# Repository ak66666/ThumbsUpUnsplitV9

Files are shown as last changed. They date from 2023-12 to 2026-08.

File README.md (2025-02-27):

# ThumbsUp! v9 ProMicro-Compatible MCU, Kailh Choc Switches

Multilevel 44/46 Key Contoured Keyboard.
2- or 3-key Thumb Cluster.

* ProMicro pin-compatible MCUs: Atmega32U4, RP2040
* Nice!nano (oritinal and clones) with battery for the bluetooth connectivity, power switch is supposed to be used.
* Supports ProGlide Cirque touchpad.
* Hot swap sockets for switches.
* Compact key spacing (18x17), large MX-size caps won't fit.

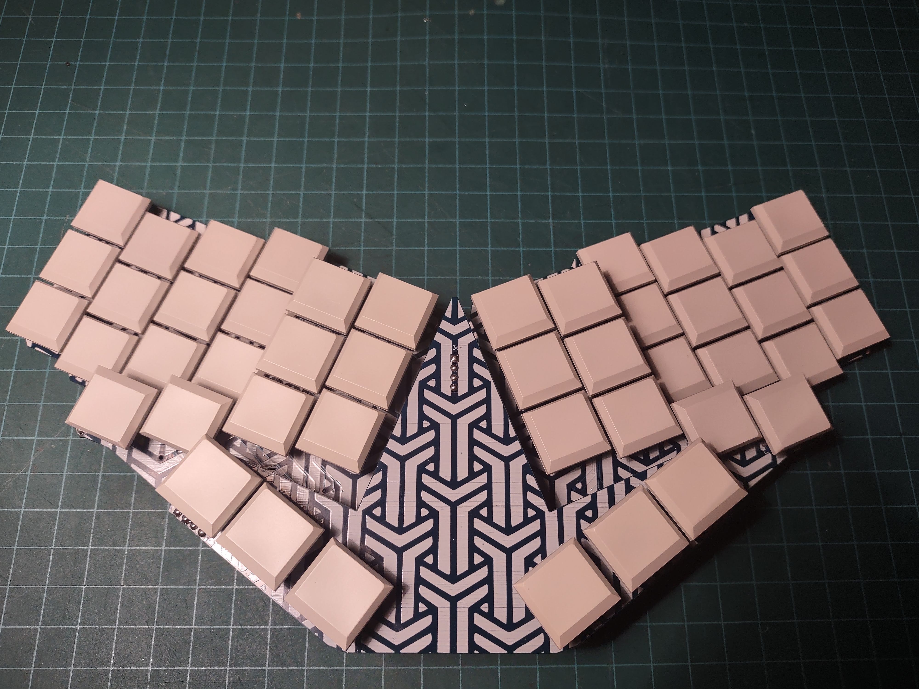
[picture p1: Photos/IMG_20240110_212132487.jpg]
Main view

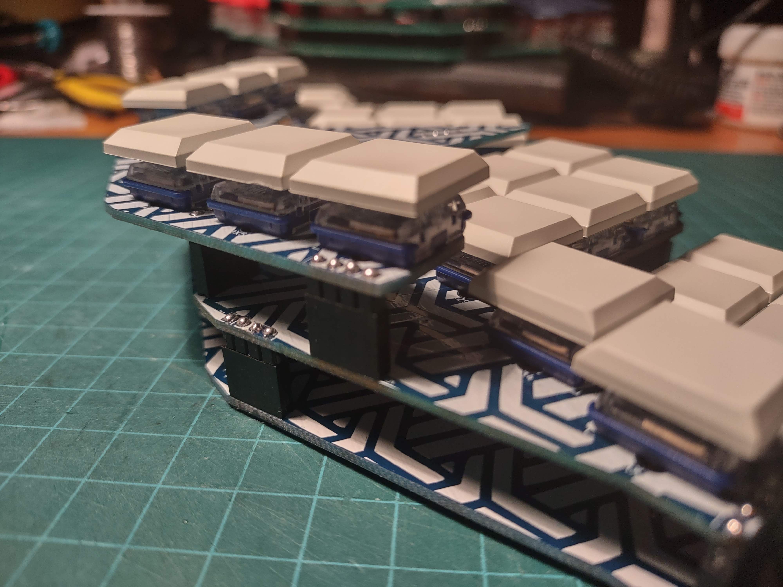
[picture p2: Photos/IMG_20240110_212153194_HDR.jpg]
3-key cluster stick out/hangs over the other plates


Other pictures in Photos folder.

# Firmware

Please refer to this article:
https://thumbsupkeyboards.blogspot.com/2024/02/source-files-and-default-firmware.html

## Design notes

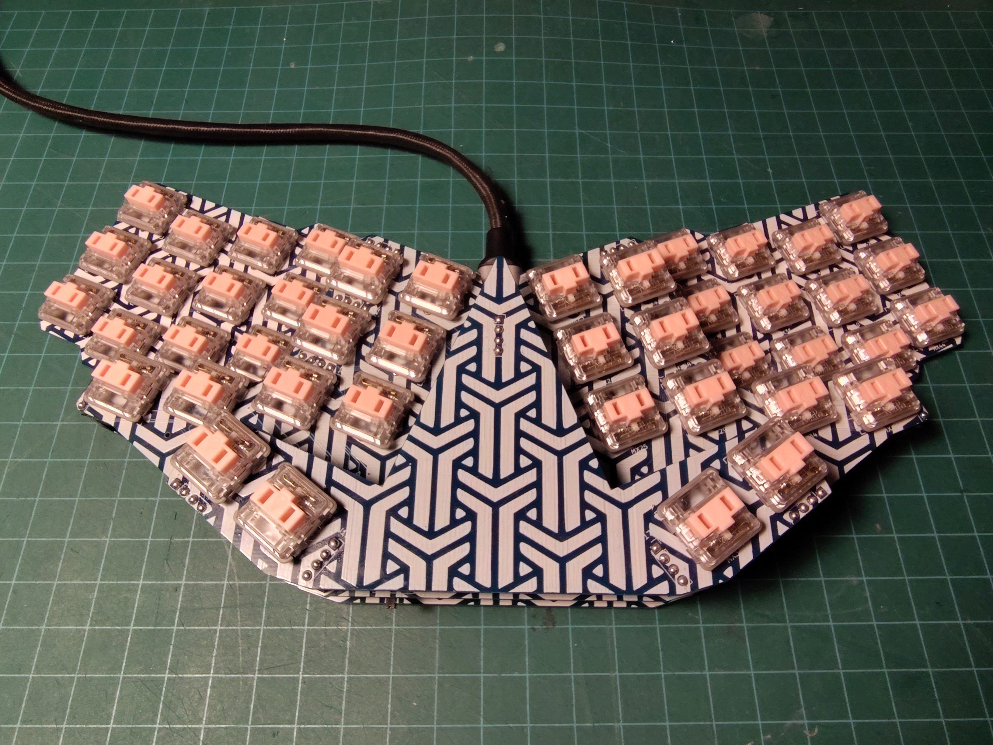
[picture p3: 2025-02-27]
Photos/IMG_20240401_223307706_HDR.jpg

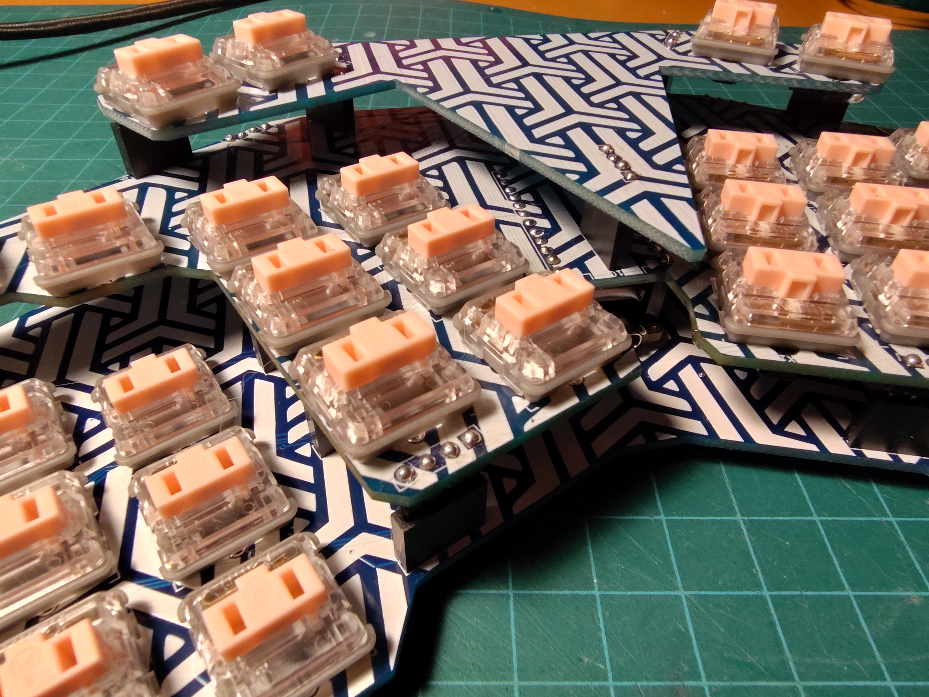
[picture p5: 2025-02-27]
Photos/IMG_20240401_223326087_HDR.jpg

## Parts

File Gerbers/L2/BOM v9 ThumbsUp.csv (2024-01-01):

Designator | Footprint | Comment
D46,D45,D44,D43,D42,D41,D40,D39,D38,D37,D36,D35,D34,D33,D32,D31,D30,D29,D28,D27,D26,D25,D24,D23,D22,D21,D20,D19,D18,D17,D16,D15,D14,D13,D12,D11,D10,D9,D8,D7,D6,D5,D4,D3,D2,D1 | D_SOD-123 | D_Small
R2,R1 | R_0805_2012Metric | 5.1K

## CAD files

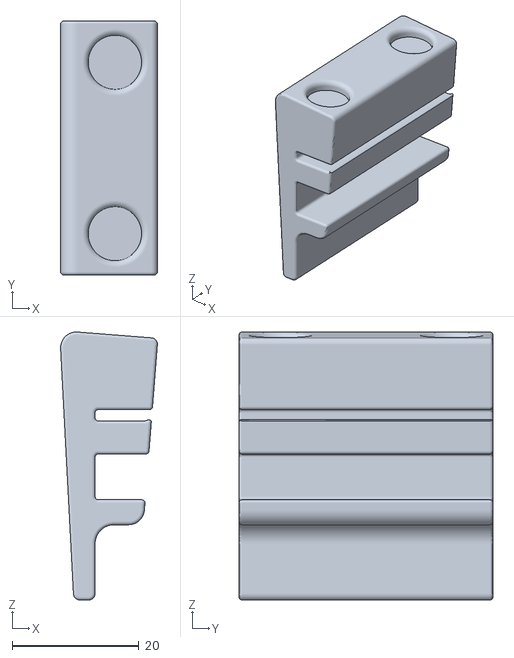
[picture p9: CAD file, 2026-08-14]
3D_parts/TU Heel.stl
15.3 x 40.0 x 42.2

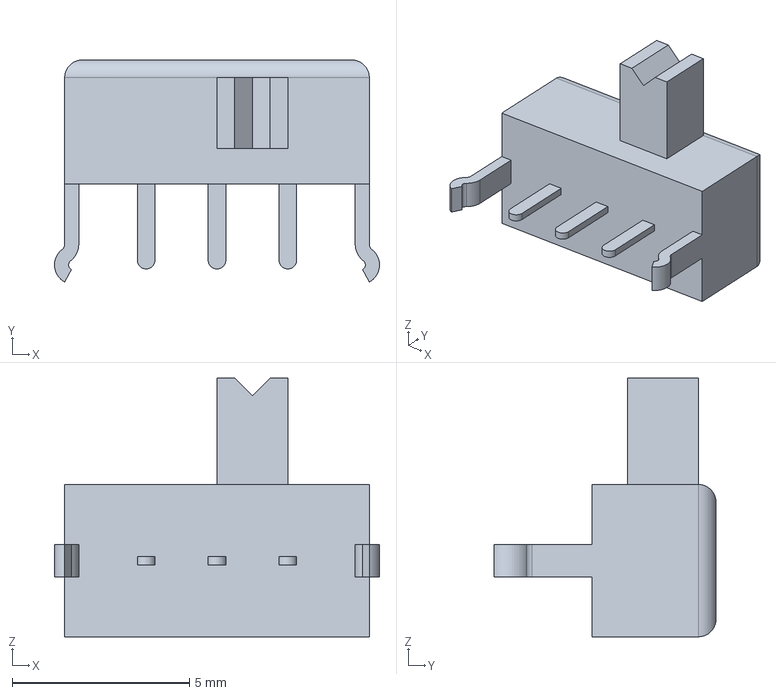
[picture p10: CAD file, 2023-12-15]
1825232-1/3D/1825232-1.stp
9.17 x 6.27 x 7.30 mm

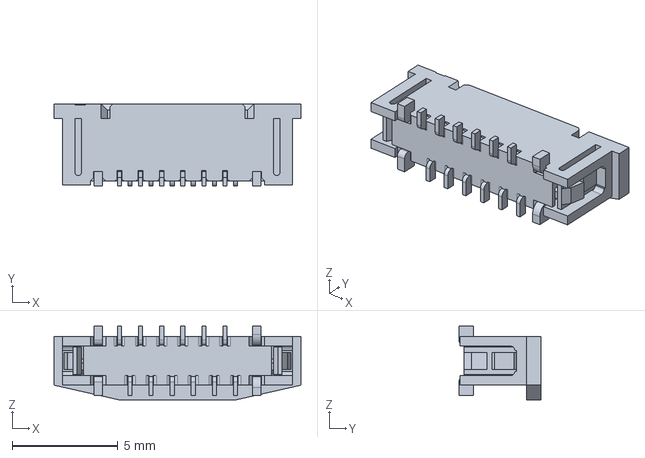
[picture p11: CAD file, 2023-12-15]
Molex 52559-1233/52559-1233/3D/52559-1233.stp
11.7 x 3.90 x 3.50 mm

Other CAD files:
1825232-1/Allegro/18252321.psm
1825232-1/DEHDL/1825232_1/chips/chips.prt
Molex 52559-1233/52559-1233/Allegro/525591233.psm
Molex 52559-1233/52559-1233/DEHDL/52559_1233/chips/chips.prt

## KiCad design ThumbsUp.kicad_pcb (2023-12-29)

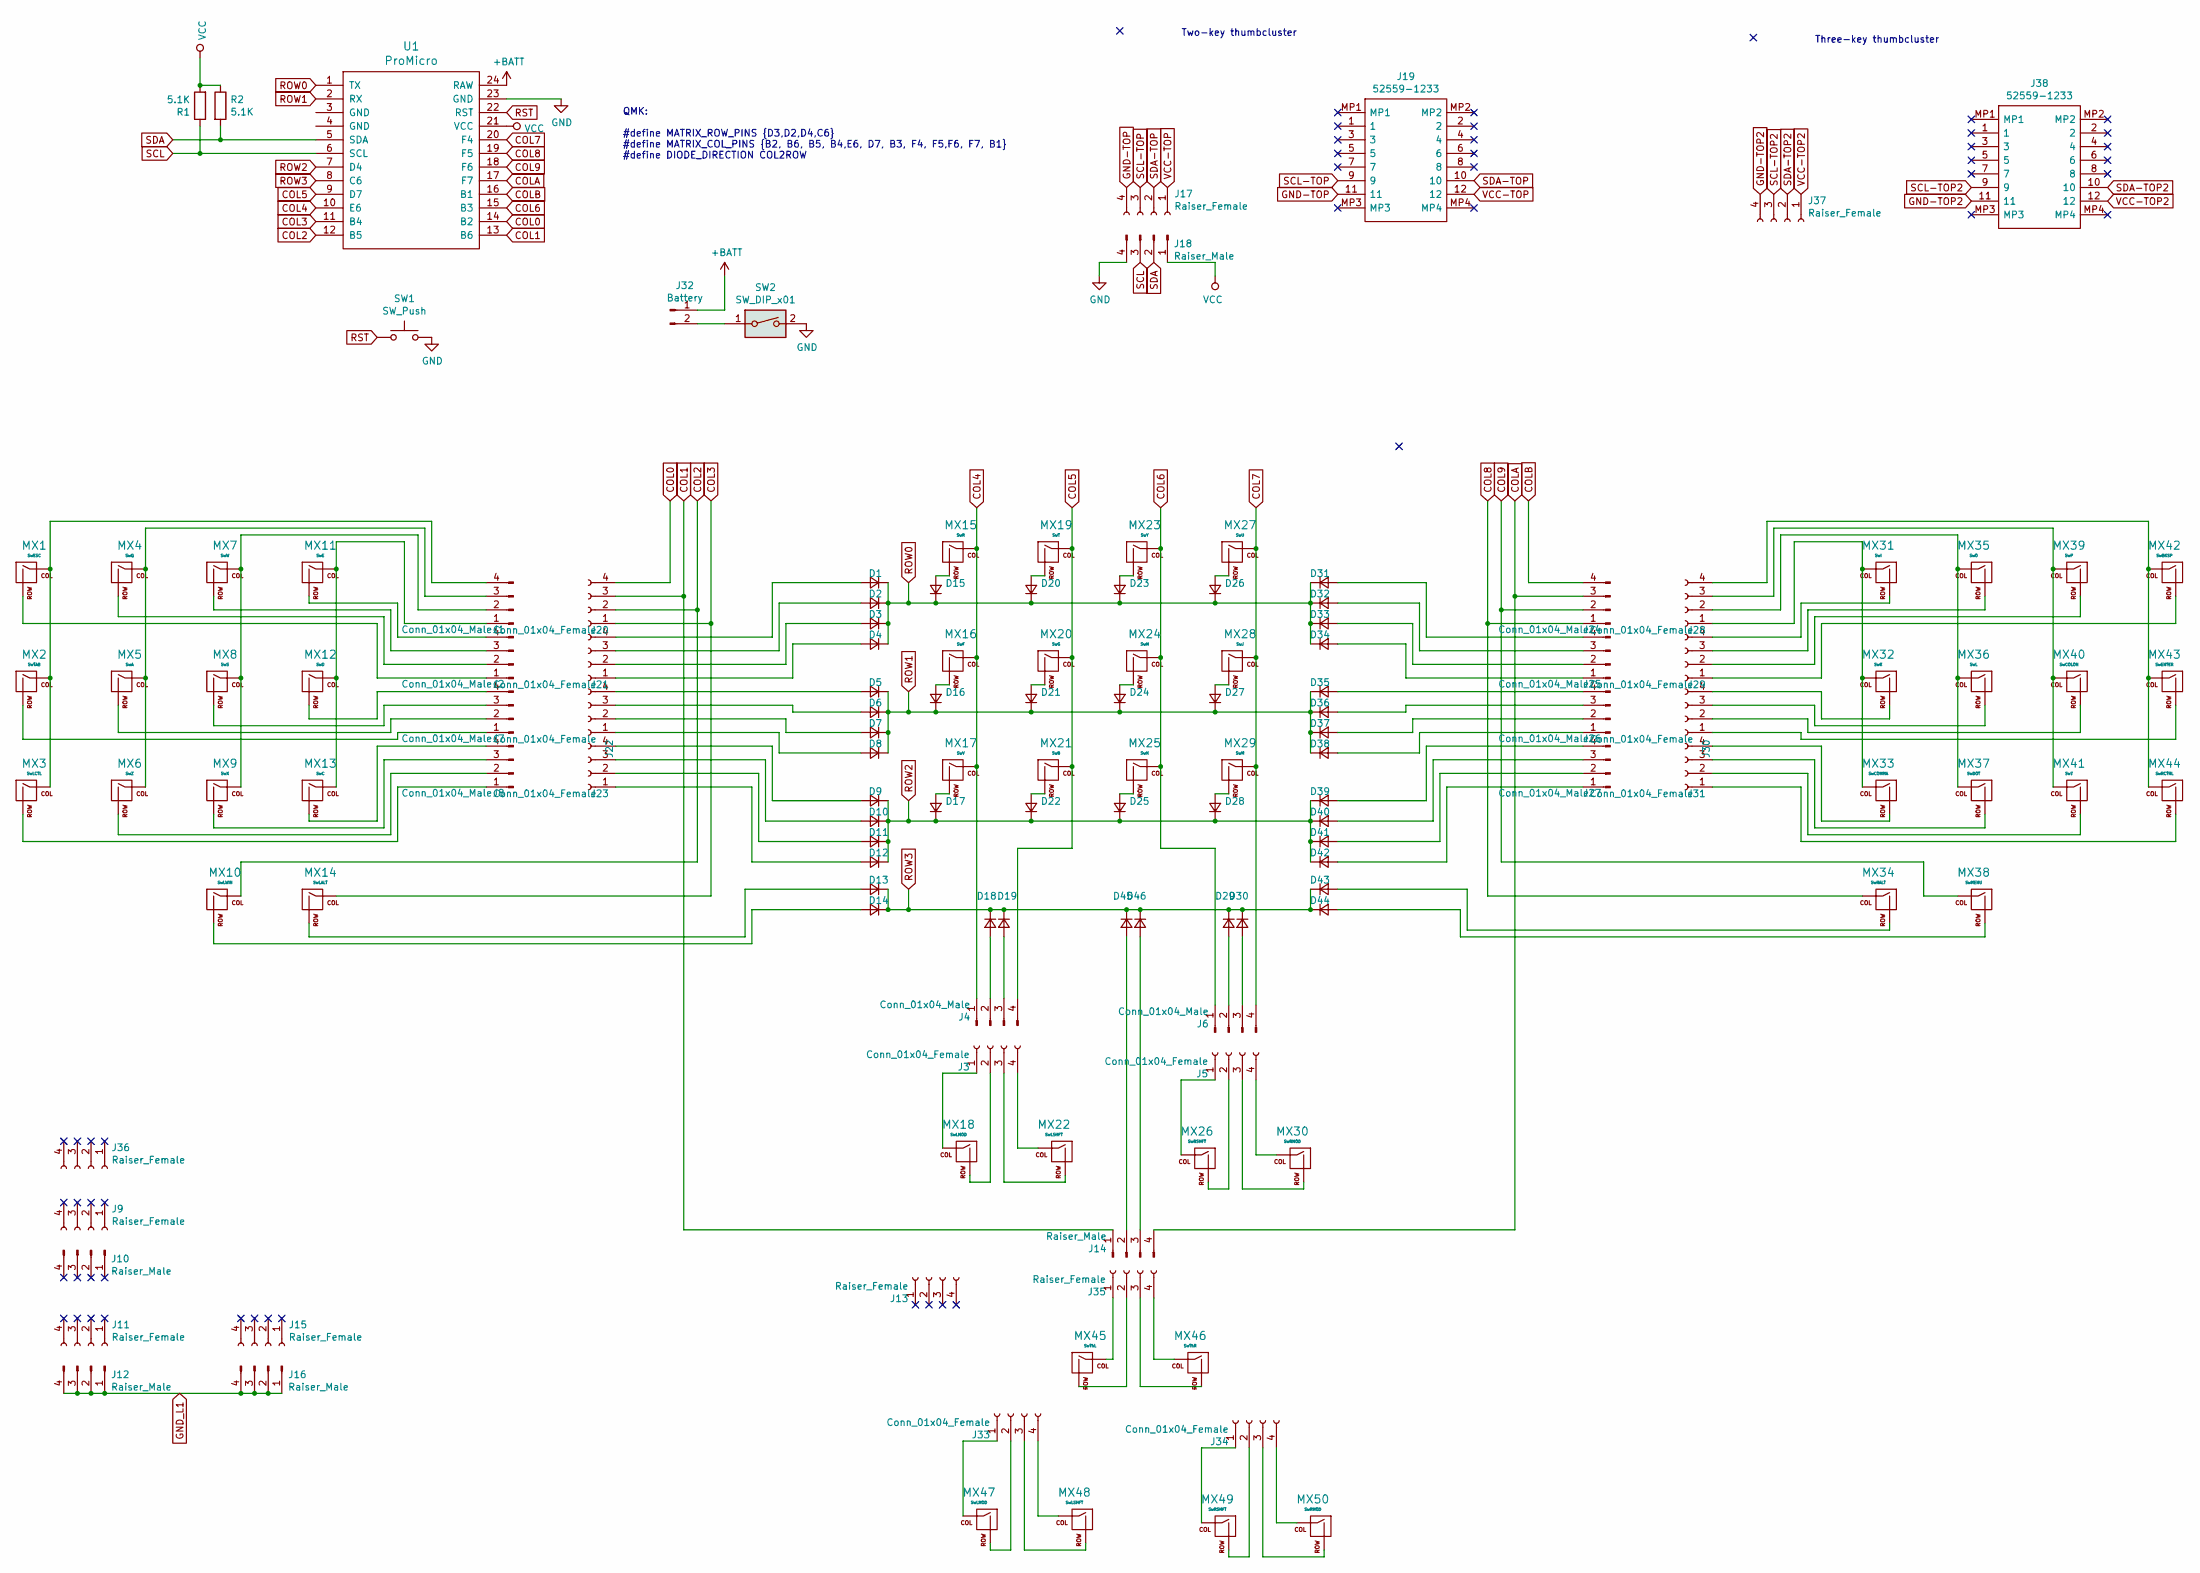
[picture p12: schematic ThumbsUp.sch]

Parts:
D1, D2, D3, D4, D5, D6, D7, D8, D9, D10, D11, D12, D13, D14, D15, D16, D17, D18, D19, D20, D21, D22, D23, D24, D25, D26, D27, D28, D29, D30, D31, D32, D33, D34, D35, D36, D37, D38, D39, D40, D41, D42, D43, D44, D45, D46: D_Small; D_SOD-123
J1, J2, J4, J6, J7, J8, J24, J25, J26, J27: Conn_01x04_Male; PinHeader_1x04_P2.54mm_Vertical
J3, J5, J20, J21, J22, J23, J28, J29, J30, J31, J33, J34: Conn_01x04_Female; PinSocket_1x04_P2.54mm_Vertical
J9, J11, J13, J15, J17, J35, J36, J37: Raiser_Female; PinSocket_1x04_P2.54mm_Vertical
J10, J12, J14, J16, J18: Raiser_Male; PinHeader_1x04_P2.54mm_Vertical
J19, J38: 52559-1233; 525591233; Mouser Part Number 538-52559-1233
J32: Battery; PinHeader_1x02_P2.54mm_Vertical
MX1: SwESC; Kailh_socket_PG1350_optional
MX2: SwTAB; Kailh_socket_PG1350_optional
MX3: SwLCTL; Kailh_socket_PG1350_optional
MX4: SwQ; Kailh_socket_PG1350_optional
MX5: SwA; Kailh_socket_PG1350_optional
MX6: SwZ; Kailh_socket_PG1350_optional
MX7: SwW; Kailh_socket_PG1350_optional
MX8: SwS; Kailh_socket_PG1350_optional
MX9: SwX; Kailh_socket_PG1350_optional
MX10: SwLWIN; Kailh_socket_PG1350_optional
MX11: SwE; Kailh_socket_PG1350_optional
MX12: SwD; Kailh_socket_PG1350_optional
MX13: SwC; Kailh_socket_PG1350_optional
MX14: SwLALT; Kailh_socket_PG1350_optional
MX15: SwR; Kailh_socket_PG1350_optional
MX16: SwF; Kailh_socket_PG1350_optional
MX17: SwV; Kailh_socket_PG1350_optional
MX18, MX47: SwLMOD; Kailh_socket_PG1350_optional
MX19: SwT; Kailh_socket_PG1350_optional
MX20: SwG; Kailh_socket_PG1350_optional
MX21: SwB; Kailh_socket_PG1350_optional
MX22, MX48: SwLSHFT; Kailh_socket_PG1350_optional
MX23: SwY; Kailh_socket_PG1350_optional
MX24: SwH; Kailh_socket_PG1350_optional
MX25: SwN; Kailh_socket_PG1350_optional
MX26, MX49: SwRSHFT; Kailh_socket_PG1350_optional
MX27: SwU; Kailh_socket_PG1350_optional
MX28: SwJ; Kailh_socket_PG1350_optional
MX29: SwM; Kailh_socket_PG1350_optional
MX30, MX50: SwRMOD; Kailh_socket_PG1350_optional
MX31: SwI; Kailh_socket_PG1350_optional
MX32: SwK; Kailh_socket_PG1350_optional
MX33: SwCOMMA; Kailh_socket_PG1350_optional
MX34: SwRALT; Kailh_socket_PG1350_optional
MX35: SwO; Kailh_socket_PG1350_optional
MX36: SwL; Kailh_socket_PG1350_optional
MX37: SwDOT; Kailh_socket_PG1350_optional
MX38: SwMENU; Kailh_socket_PG1350_optional
MX39: SwP; Kailh_socket_PG1350_optional
MX40: SwCOLON; Kailh_socket_PG1350_optional
MX41: Sw?; Kailh_socket_PG1350_optional
MX42: SwBKSP; Kailh_socket_PG1350_optional
MX43: SwENTER; Kailh_socket_PG1350_optional
MX44: SwRCTRL; Kailh_socket_PG1350_optional
MX45: SwThL; Kailh_socket_PG1350_optional
MX46: SwThR; Kailh_socket_PG1350_optional
R1, R2: 5.1K; R_0805_2012Metric
SW1: SW_Push; SKQG-1155865
SW2: SW_DIP_x01; 18252321
U1: ProMicro

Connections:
+BATT: J32.1, U1.24 (RAW)
COL0: J20.4, U1.14 (B2)
COL1: J14.1, J20.3, U1.13 (B6)
COL2: J20.2, MX10.1 (COL), U1.12 (B5)
COL3: J20.1, MX14.1 (COL), U1.11 (B4)
COL4: J4.1, MX15.1 (COL), MX16.1 (COL), MX17.1 (COL), U1.10 (E6)
COL5: J4.4, MX19.1 (COL), MX20.1 (COL), MX21.1 (COL), U1.9 (D7)
COL6: J6.1, MX23.1 (COL), MX24.1 (COL), MX25.1 (COL), U1.15 (B3)
COL7: J6.4, MX27.1 (COL), MX28.1 (COL), MX29.1 (COL), U1.20 (F4)
COL8: J24.1, MX34.1 (COL), U1.19 (F5)
COL9: J24.2, MX38.1 (COL), U1.18 (F6)
COLA: J14.4, J24.3, U1.17 (F7)
COLB: J24.4, U1.16 (B1)
GND: J18.4, SW1.2, SW2.2, U1.23 (GND)
GND-TOP: J17.4, J19.11
GND-TOP2: J37.4, J38.11
GND_L1: J12.1, J12.2, J12.3, J12.4, J16.1, J16.2, J16.3, J16.4
unnamed: D1.2 (A), J21.4
unnamed: D2.2 (A), J21.3
unnamed: D3.2 (A), J21.2
unnamed: D4.2 (A), J21.1
unnamed: D5.2 (A), J22.4
unnamed: D6.2 (A), J22.3
unnamed: D7.2 (A), J22.2
unnamed: D8.2 (A), J22.1
unnamed: D9.2 (A), J23.4
unnamed: D10.2 (A), J23.3
unnamed: D11.2 (A), J23.2
unnamed: D12.2 (A), J23.1
unnamed: D13.2 (A), MX14.2 (ROW)
unnamed: D14.2 (A), MX10.2 (ROW)
unnamed: D15.2 (A), MX15.2 (ROW)
unnamed: D16.2 (A), MX16.2 (ROW)
unnamed: D17.2 (A), MX17.2 (ROW)
unnamed: D18.2 (A), J4.2
unnamed: D19.2 (A), J4.3
unnamed: D20.2 (A), MX19.2 (ROW)
unnamed: D21.2 (A), MX20.2 (ROW)
unnamed: D22.2 (A), MX21.2 (ROW)
unnamed: D23.2 (A), MX23.2 (ROW)
unnamed: D24.2 (A), MX24.2 (ROW)
unnamed: D25.2 (A), MX25.2 (ROW)
unnamed: D26.2 (A), MX27.2 (ROW)
unnamed: D27.2 (A), MX28.2 (ROW)
unnamed: D28.2 (A), MX29.2 (ROW)
unnamed: D29.2 (A), J6.2
unnamed: D30.2 (A), J6.3
unnamed: D31.2 (A), J25.4
unnamed: D32.2 (A), J25.3
unnamed: D33.2 (A), J25.2
unnamed: D34.2 (A), J25.1
unnamed: D35.2 (A), J26.4
unnamed: D36.2 (A), J26.3
unnamed: D37.2 (A), J26.2
unnamed: D38.2 (A), J26.1
unnamed: D39.2 (A), J27.4
unnamed: D40.2 (A), J27.3
unnamed: D41.2 (A), J27.2
unnamed: D42.2 (A), J27.1
unnamed: D43.2 (A), MX34.2 (ROW)
unnamed: D44.2 (A), MX38.2 (ROW)
unnamed: D45.2 (A), J14.2
unnamed: D46.2 (A), J14.3
unnamed: J1.1, MX11.1 (COL), MX12.1 (COL), MX13.1 (COL)
unnamed: J1.2, MX7.1 (COL), MX8.1 (COL), MX9.1 (COL)
unnamed: J1.3, MX4.1 (COL), MX5.1 (COL), MX6.1 (COL)
unnamed: J1.4, MX1.1 (COL), MX2.1 (COL), MX3.1 (COL)
unnamed: J2.1, MX1.2 (ROW)
unnamed: J2.2, MX4.2 (ROW)
unnamed: J2.3, MX7.2 (ROW)
unnamed: J2.4, MX11.2 (ROW)
unnamed: J3.1, MX18.1 (COL)
unnamed: J3.2, MX18.2 (ROW)
unnamed: J3.3, MX22.2 (ROW)
unnamed: J3.4, MX22.1 (COL)
unnamed: J5.1, MX26.1 (COL)
unnamed: J5.2, MX26.2 (ROW)
unnamed: J5.3, MX30.2 (ROW)
unnamed: J5.4, MX30.1 (COL)
unnamed: J7.1, MX2.2 (ROW)
unnamed: J7.2, MX5.2 (ROW)
unnamed: J7.3, MX8.2 (ROW)
unnamed: J7.4, MX12.2 (ROW)
unnamed: J8.1, MX3.2 (ROW)
unnamed: J8.2, MX6.2 (ROW)
unnamed: J8.3, MX9.2 (ROW)
unnamed: J8.4, MX13.2 (ROW)
unnamed: J28.1, MX31.1 (COL), MX32.1 (COL), MX33.1 (COL)
unnamed: J28.2, MX35.1 (COL), MX36.1 (COL), MX37.1 (COL)
unnamed: J28.3, MX39.1 (COL), MX40.1 (COL), MX41.1 (COL)
unnamed: J28.4, MX42.1 (COL), MX43.1 (COL), MX44.1 (COL)
unnamed: J29.1, MX42.2 (ROW)
unnamed: J29.2, MX39.2 (ROW)
unnamed: J29.3, MX35.2 (ROW)
unnamed: J29.4, MX31.2 (ROW)
unnamed: J30.1, MX43.2 (ROW)
unnamed: J30.2, MX40.2 (ROW)
unnamed: J30.3, MX36.2 (ROW)
unnamed: J30.4, MX32.2 (ROW)
unnamed: J31.1, MX44.2 (ROW)
unnamed: J31.2, MX41.2 (ROW)
unnamed: J31.3, MX37.2 (ROW)
unnamed: J31.4, MX33.2 (ROW)
unnamed: J32.2, SW2.1
unnamed: J33.1, MX47.1 (COL)
unnamed: J33.2, MX47.2 (ROW)
unnamed: J33.3, MX48.2 (ROW)
unnamed: J33.4, MX48.1 (COL)
unnamed: J34.1, MX49.1 (COL)
unnamed: J34.2, MX49.2 (ROW)
unnamed: J34.3, MX50.2 (ROW)
unnamed: J34.4, MX50.1 (COL)
unnamed: J35.1, MX45.1 (COL)
unnamed: J35.2, MX45.2 (ROW)
unnamed: J35.3, MX46.2 (ROW)
unnamed: J35.4, MX46.1 (COL)
ROW0: D1.1 (K), D2.1 (K), D3.1 (K), D4.1 (K), D15.1 (K), D20.1 (K), D23.1 (K), D26.1 (K), D31.1 (K), D32.1 (K), D33.1 (K), D34.1 (K), U1.1 (TX)
ROW1: D5.1 (K), D6.1 (K), D7.1 (K), D8.1 (K), D16.1 (K), D21.1 (K), D24.1 (K), D27.1 (K), D35.1 (K), D36.1 (K), D37.1 (K), D38.1 (K), U1.2 (RX)
ROW2: D9.1 (K), D10.1 (K), D11.1 (K), D12.1 (K), D17.1 (K), D22.1 (K), D25.1 (K), D28.1 (K), D39.1 (K), D40.1 (K), D41.1 (K), D42.1 (K), U1.7 (D4)
ROW3: D13.1 (K), D14.1 (K), D18.1 (K), D19.1 (K), D29.1 (K), D30.1 (K), D43.1 (K), D44.1 (K), D45.1 (K), D46.1 (K), U1.8 (C6)
RST: SW1.1, U1.22 (RST)
SCL: J18.3, R1.1, U1.6 (SCL)
SCL-TOP: J17.3, J19.9
SCL-TOP2: J37.3, J38.9
SDA: J18.2, R2.2, U1.5 (SDA)
SDA-TOP: J17.2, J19.10
SDA-TOP2: J37.2, J38.10
VCC: J18.1, R1.2, R2.1, U1.21 (VCC)
VCC-TOP: J17.1, J19.12
VCC-TOP2: J37.1, J38.12

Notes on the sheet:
QMK: #define MATRIX_ROW_PINS {D3,D2,D4,C6} #define MATRIX_COL_PINS {B2, B6, B5, B4,E6, D7, B3, F4, F5,F6, F7, B1} #define DIODE_DIRECTION COL2ROW
Two-key thumbcluster
Three-key thumbcluster

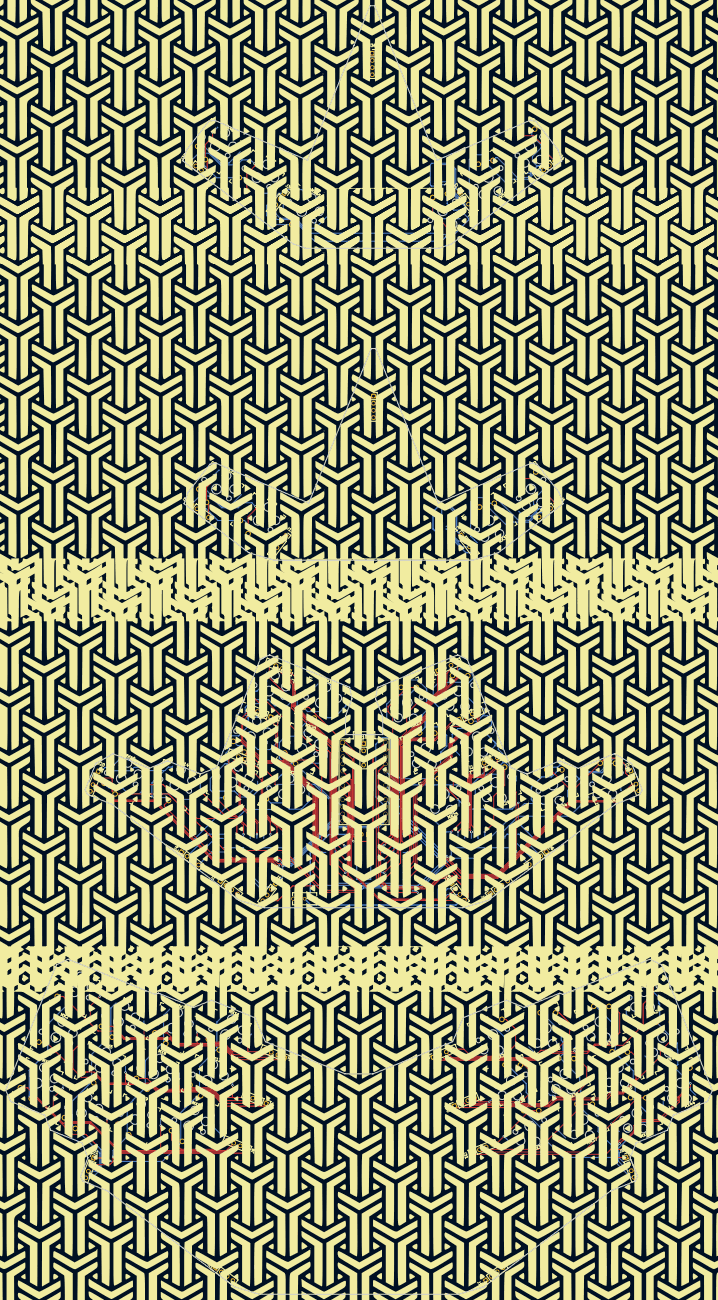
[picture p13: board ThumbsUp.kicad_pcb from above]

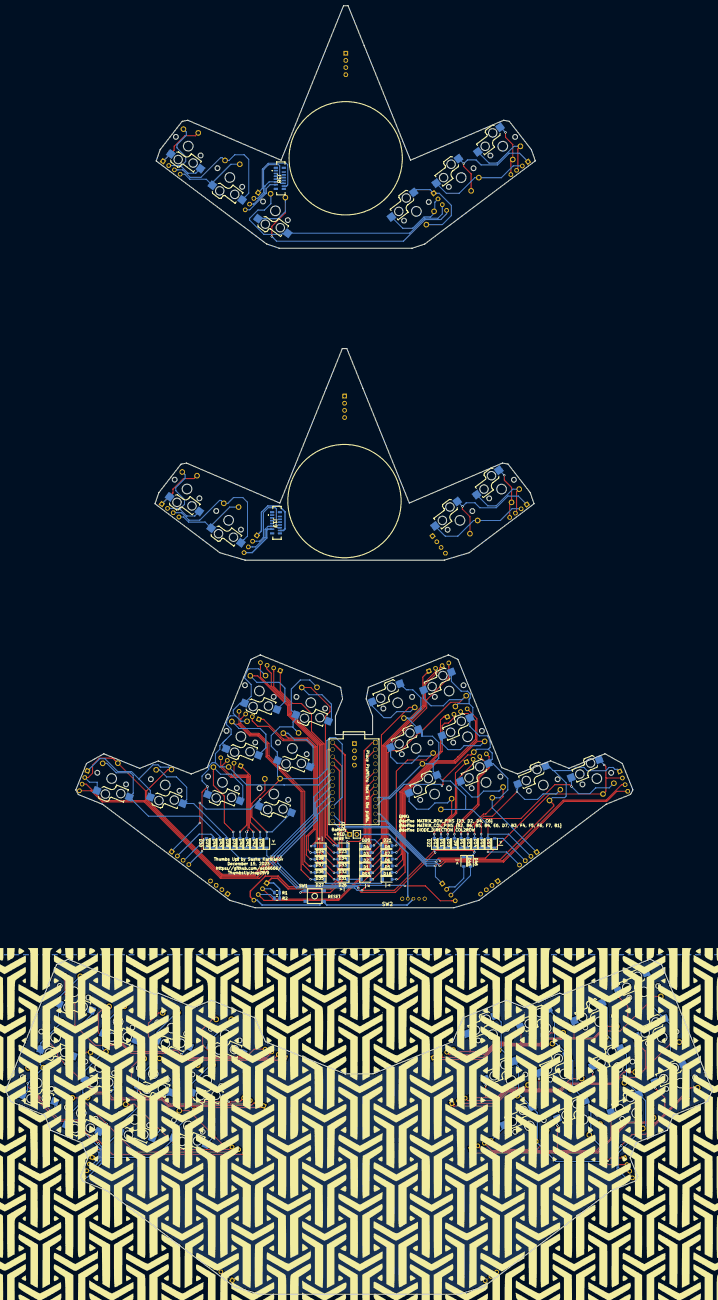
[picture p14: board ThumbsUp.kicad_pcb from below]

Board: 2 copper layers, 251.1 x 457.9 mm, 139 parts (52 on the bottom side), 130 nets.

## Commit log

2023-12-15 v9 Initial commit from v2.
    [1825232-1.SchLib, 1825232-1.stp, 18252321.PcbLib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]
2023-12-16 v9 Added the third key to the thumbcluster.
    [ThumbsUp.sch]
2023-12-27 v9 Redrew the lower PCB, added the silkscreens.
    [ThumbsUp.kicad_pcb, ThumbsUp.sch]
2024-01-01 v9 Gerbers generated
    [BOM v9 ThumbsUp.csv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]
2026-08-14 B9: Added an extended heel.
    [TU Heel.stl]
